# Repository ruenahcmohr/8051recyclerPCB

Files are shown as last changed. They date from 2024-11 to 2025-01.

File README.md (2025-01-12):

# 8051recyclerPCB
External memory card for PLCC 8051 OTP processors

PCB designed for recycling OTP PLCC 8051 chips. 

Becasue using the 8051 with external memory burns off most of the ports, I have added two chips that use the external RAM space for an input and output port. Any write to external memory will go to the dedicated output port, and any read from external memory will read the dedicated input port.

(I hope your fine with the in-chip ram :] )

ERATTA:

- The output chip needs to be 74xx374 or another pin compatible chip but sure the heck not the 74xx373
- Oh, maybe those serial leds ought to be active low eh?
- Ya know that trace to that top decoupling cap dunn't need to be only 10 thou.

IMPROVA:

- Could there please be a mark on the common cathode pin of that damn led?
- Could someone please mark the xtal pin for extern clock input?
- Ya know that trace to that top decoupling cap dunn't need to be only 10 thou.
- break out pins 1, 12, 23, 34 to pads incase they need bodge connections
- align the pin 27 connection with VCC for easier bridging to use 2764 roms. (haha wait no, there are only 28 pins)

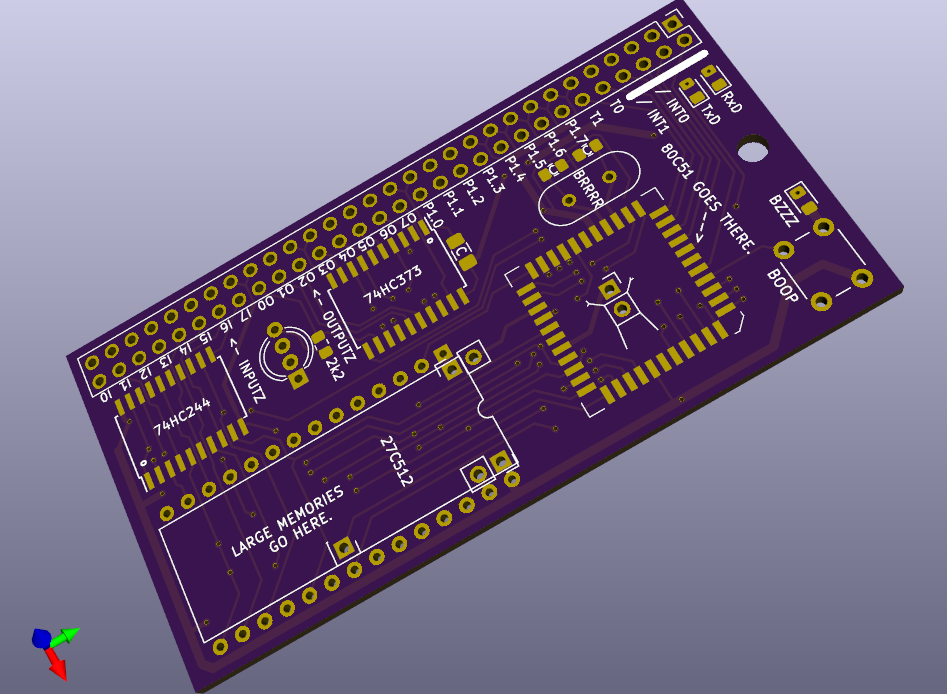
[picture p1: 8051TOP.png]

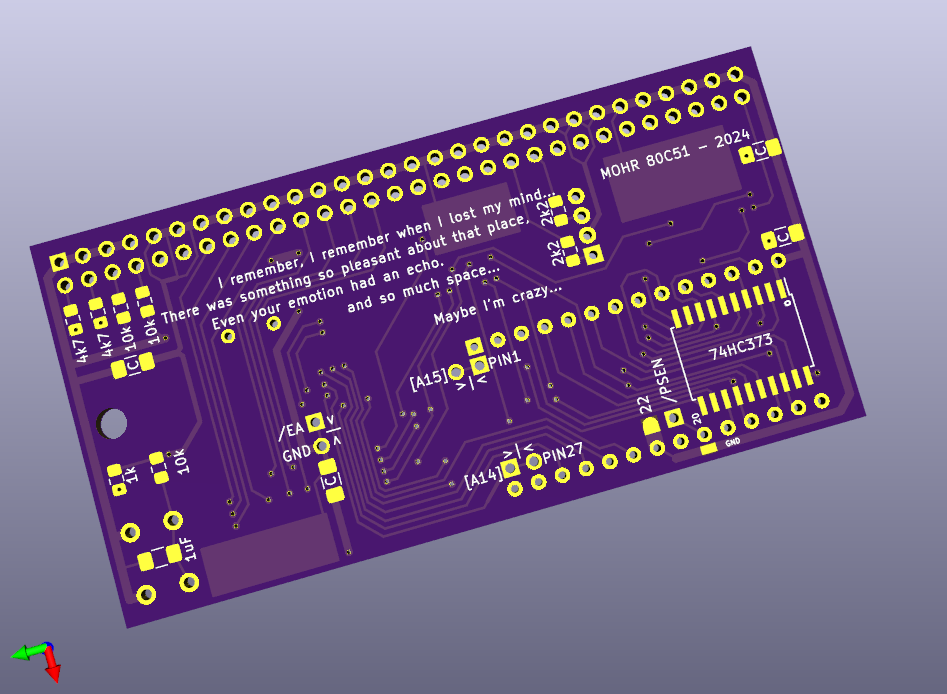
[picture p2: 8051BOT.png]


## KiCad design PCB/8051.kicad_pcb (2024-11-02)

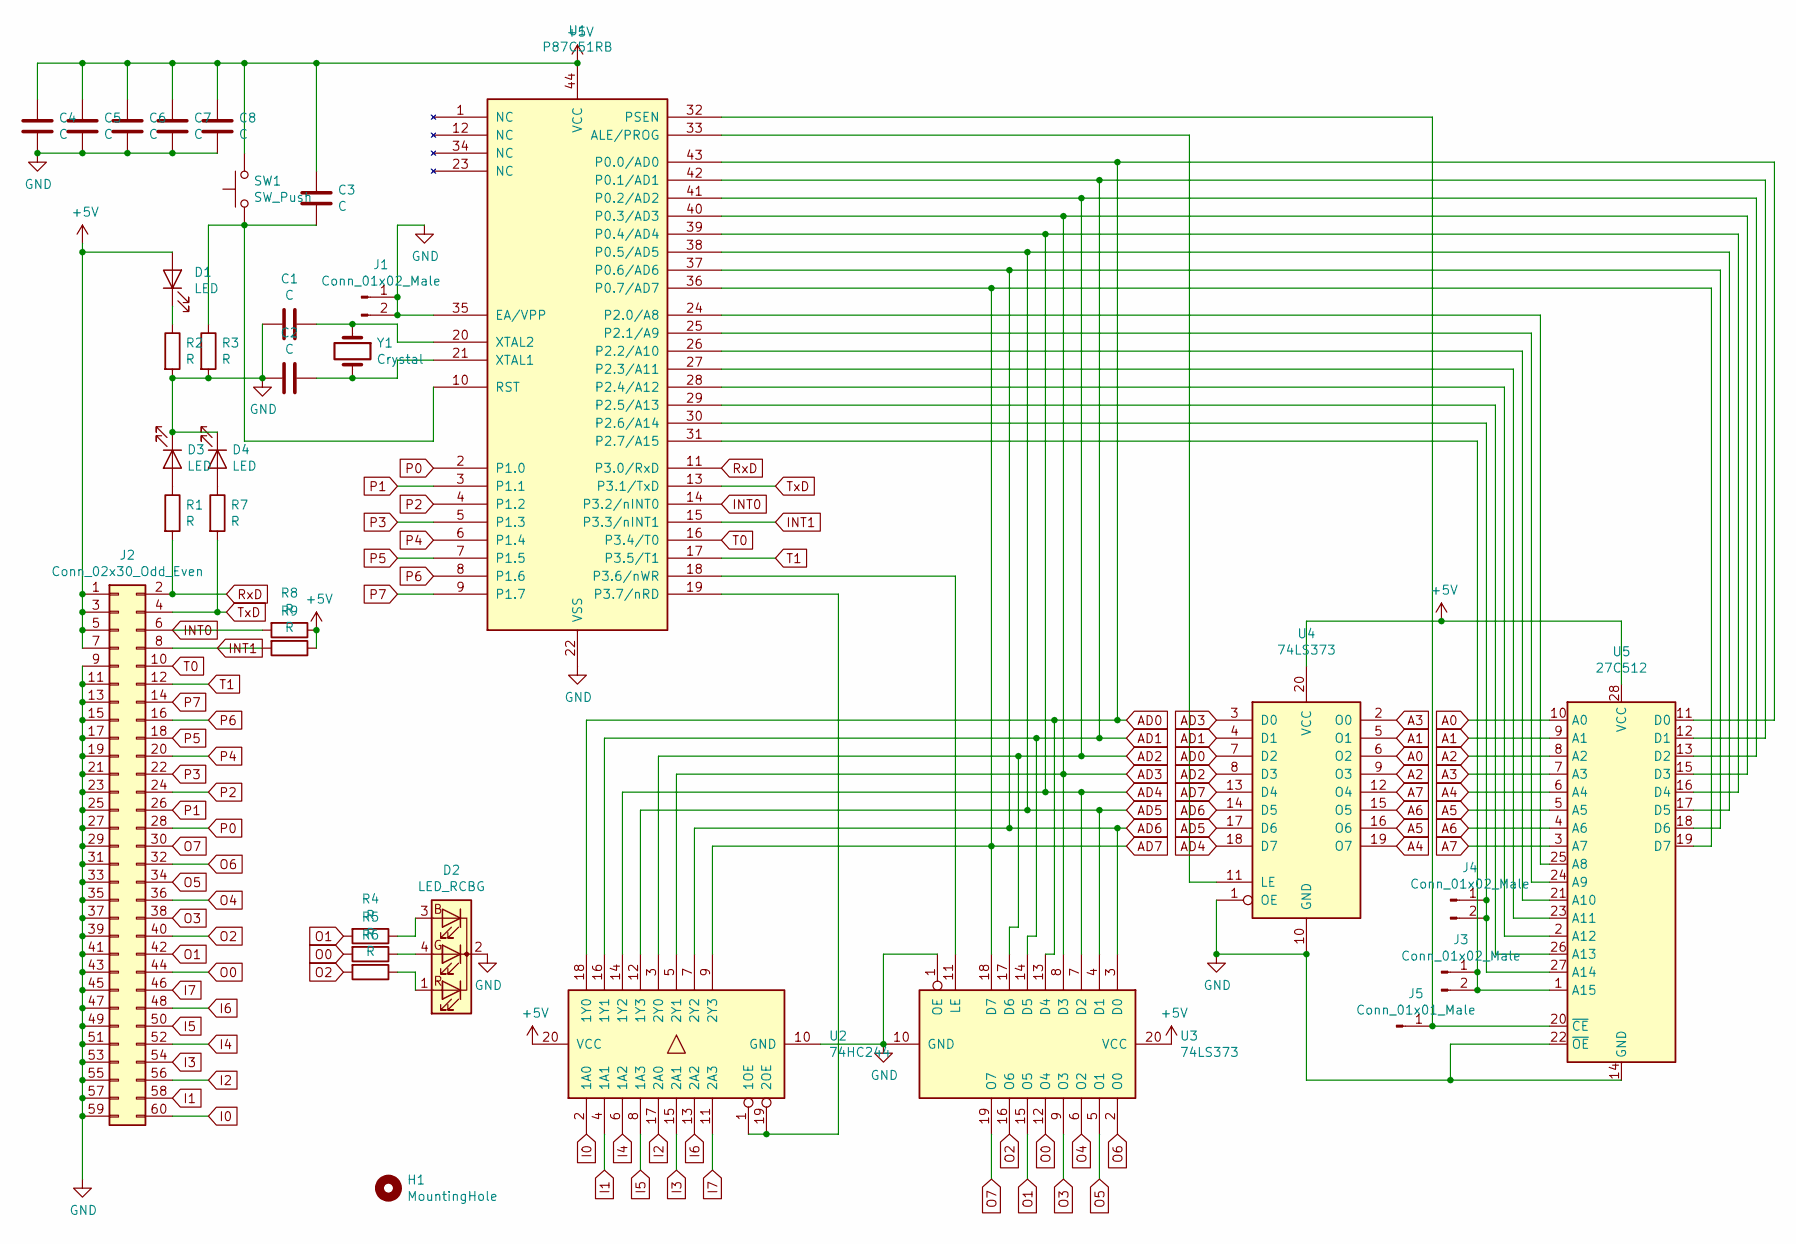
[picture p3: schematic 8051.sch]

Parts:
C1, C2: C; C_0805_2012Metric_Pad1.15x1.40mm_HandSolder
C3, C4, C5, C6, C7, C8: C; C_1206_3216Metric_Pad1.42x1.75mm_HandSolder
D1, D3, D4: LED; LED_0805_2012Metric_Pad1.15x1.40mm_HandSolder
D2: LED_RCBG; LED_D5.0mm-4_RGB_Wide_Pins
H1: MountingHole; MountingHole_3.2mm_M3
J1, J3, J4: Conn_01x02_Male; PinSocket_1x02_P2.54mm_Vertical
J2: Conn_02x30_Odd_Even; PinHeader_2x30_P2.54mm_Vertical
J5: Conn_01x01_Male; PinSocket_1x01_P2.54mm_Vertical
R1, R2, R3, R4, R5, R6, R7, R8, R9: R; R_0805_2012Metric_Pad1.15x1.40mm_HandSolder
SW1: SW_Push; SW_PUSH_6mm
U1: P87C51RB; PLCC-44
U2: 74HC244; SOIC-20W_7.5x12.8mm_P1.27mm
U3, U4: 74LS373; SOIC-20W_7.5x12.8mm_P1.27mm
U5: 27C512; DIP-28_W15.24mm
Y1: Crystal; Crystal_HC49-4H_Vertical

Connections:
+5V: C3.1, C4.1, C5.1, C6.1, C7.1, C8.1, D1.2 (A), J2.1, J2.3, J2.5, J2.7, R8.1, R9.1, SW1.1, U1.44 (VCC), U2.20 (VCC), U3.20 (VCC), U4.20 (VCC), U5.28 (VCC)
A0: U4.6 (O2), U5.10 (A0)
A1: U4.5 (O1), U5.9 (A1)
A2: U4.9 (O3), U5.8 (A2)
A3: U4.2 (O0), U5.7 (A3)
A4: U4.19 (O7), U5.6 (A4)
A5: U4.16 (O6), U5.5 (A5)
A6: U4.15 (O5), U5.4 (A6)
A7: U4.12 (O4), U5.3 (A7)
AD0: U1.43 (P0.0/AD0), U2.18 (1Y0), U3.13 (D4), U4.7 (D2), U5.11 (D0)
AD1: U1.42 (P0.1/AD1), U2.16 (1Y1), U3.14 (D5), U4.4 (D1), U5.12 (D1)
AD2: U1.41 (P0.2/AD2), U2.3 (2Y0), U3.17 (D6), U4.8 (D3), U5.13 (D2)
AD3: U1.40 (P0.3/AD3), U2.5 (2Y1), U3.8 (D3), U4.3 (D0), U5.15 (D3)
AD4: U1.39 (P0.4/AD4), U2.14 (1Y2), U3.7 (D2), U4.18 (D7), U5.16 (D4)
AD5: U1.38 (P0.5/AD5), U2.12 (1Y3), U3.4 (D1), U4.17 (D6), U5.17 (D5)
AD6: U1.37 (P0.6/AD6), U2.7 (2Y2), U3.3 (D0), U4.14 (D5), U5.18 (D6)
AD7: U1.36 (P0.7/AD7), U2.9 (2Y3), U3.18 (D7), U4.13 (D4), U5.19 (D7)
GND: C1.2, C2.2, C4.2, C5.2, C6.2, C7.2, C8.2, D2.2 (K), D3.1 (K), D4.1 (K), J1.1, J1.2, J2.9, J2.11, J2.13, J2.15, J2.17, J2.19, J2.21, J2.23, J2.25, J2.27, J2.29, J2.31, J2.33, J2.35, J2.37, J2.39, J2.41, J2.43, J2.45, J2.47, J2.49, J2.51, J2.53, J2.55, J2.57, J2.59, R2.2, R3.2, U1.22 (VSS), U1.35 (EA/VPP), U2.10 (GND), U3.1 (OE), U3.10 (GND), U4.1 (OE), U4.10 (GND), U5.14 (GND), U5.22 (~OE)
I0: J2.60, U2.2 (1A0)
I1: J2.58, U2.4 (1A1)
I2: J2.56, U2.17 (2A0)
I3: J2.54, U2.15 (2A1)
I4: J2.52, U2.6 (1A2)
I5: J2.50, U2.8 (1A3)
I6: J2.48, U2.13 (2A2)
I7: J2.46, U2.11 (2A3)
INT0: J2.6, R8.2, U1.14 (P3.2/nINT0)
INT1: J2.8, R9.2, U1.15 (P3.3/nINT1)
unnamed: C1.1, U1.20 (XTAL2), Y1.1
unnamed: C2.1, U1.21 (XTAL1), Y1.2
unnamed: C3.2, R3.1, SW1.2, U1.10 (RST)
unnamed: D1.1 (K), R2.1
unnamed: D2.1 (RA), R6.1
unnamed: D2.3 (BA), R4.1
unnamed: D2.4 (GA), R5.1
unnamed: D3.2 (A), R1.1
unnamed: D4.2 (A), R7.1
unnamed: J3.1, J3.2, U1.31 (P2.7/A15), U5.1 (A15)
unnamed: J4.1, J4.2, U1.30 (P2.6/A14), U5.27 (A14)
unnamed: J5.1, U1.32 (PSEN), U5.20 (~CE)
unnamed: U1.18 (P3.6/nWR), U3.11 (LE)
unnamed: U1.19 (P3.7/nRD), U2.1 (1OE), U2.19 (2OE)
unnamed: U1.24 (P2.0/A8), U5.25 (A8)
unnamed: U1.25 (P2.1/A9), U5.24 (A9)
unnamed: U1.26 (P2.2/A10), U5.21 (A10)
unnamed: U1.27 (P2.3/A11), U5.23 (A11)
unnamed: U1.28 (P2.4/A12), U5.2 (A12)
unnamed: U1.29 (P2.5/A13), U5.26 (A13)
unnamed: U1.33 (ALE/PROG), U4.11 (LE)
O0: J2.44, R5.2, U3.12 (O4)
O1: J2.42, R4.2, U3.15 (O5)
O2: J2.40, R6.2, U3.16 (O6)
O3: J2.38, U3.9 (O3)
O4: J2.36, U3.6 (O2)
O5: J2.34, U3.5 (O1)
O6: J2.32, U3.2 (O0)
O7: J2.30, U3.19 (O7)
P0: J2.28, U1.2 (P1.0)
P1: J2.26, U1.3 (P1.1)
P2: J2.24, U1.4 (P1.2)
P3: J2.22, U1.5 (P1.3)
P4: J2.20, U1.6 (P1.4)
P5: J2.18, U1.7 (P1.5)
P6: J2.16, U1.8 (P1.6)
P7: J2.14, U1.9 (P1.7)
RxD: J2.2, R1.2, U1.11 (P3.0/RxD)
T0: J2.10, U1.16 (P3.4/T0)
T1: J2.12, U1.17 (P3.5/T1)
TxD: J2.4, R7.2, U1.13 (P3.1/TxD)

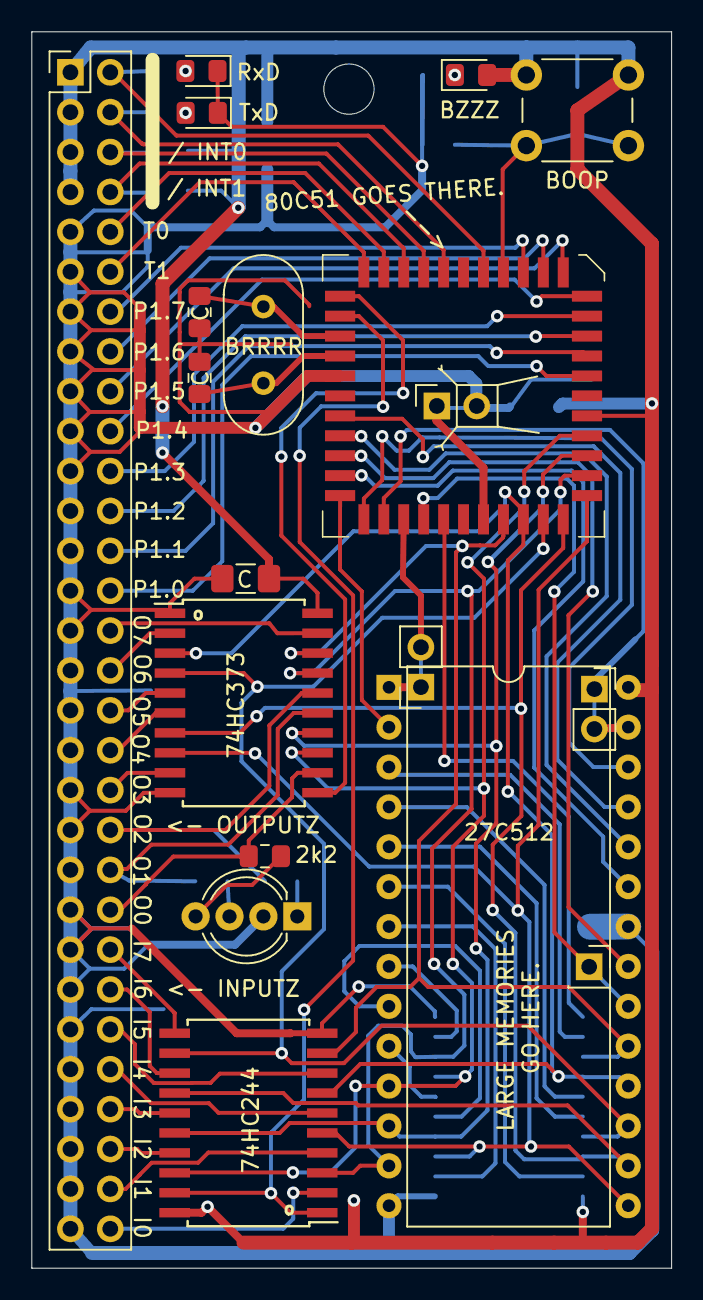
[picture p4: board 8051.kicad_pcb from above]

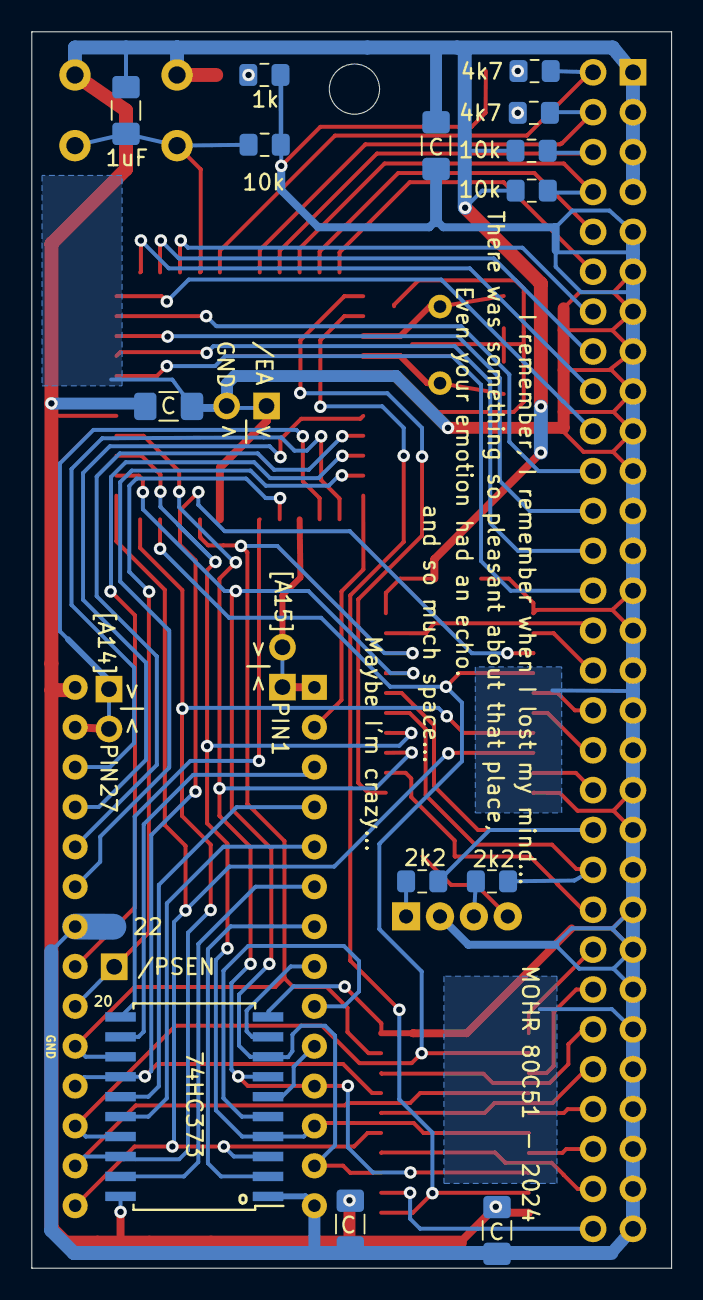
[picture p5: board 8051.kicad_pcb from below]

Board: 2 copper layers, 40.8 x 78.8 mm, 34 parts (14 on the bottom side), 69 nets.

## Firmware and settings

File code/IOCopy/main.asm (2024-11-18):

;--------------------------------------------------------
; File Created by SDCC : free open source ANSI-C Compiler
; Version 4.0.0 #11528 (Linux)
;--------------------------------------------------------
	.module main
	.optsdcc -mmcs51 --model-small
	
;--------------------------------------------------------
; Public variables in this module
;--------------------------------------------------------
	.globl _main
	.globl _Delay
	.globl _B_7
	.globl _B_6
	.globl _B_5
	.globl _B_4
	.globl _B_3
	.globl _B_2
	.globl _B_1
	.globl _B_0
	.globl _ACC_7
	.globl _ACC_6
	.globl _ACC_5
	.globl _ACC_4
	.globl _ACC_3
	.globl _ACC_2
	.globl _ACC_1
	.globl _ACC_0
	.globl _CF
	.globl _CR
	.globl _CCF4
	.globl _CCF3
	.globl _CCF2
	.globl _CCF1
	.globl _CCF0
	.globl _CY
	.globl _AC
	.globl _F0
	.globl _RS1
	.globl _RS0
	.globl _OV
	.globl _P
	.globl _TF2
	.globl _EXF2
	.globl _RCLK
	.globl _TCLK
	.globl _EXEN2
	.globl _TR2
	.globl _C_T2
	.globl _CP_RL2
	.globl _PPC
	.globl _PT2
	.globl _PS
	.globl _PT1
	.globl _PX1
	.globl _PT0
	.globl _PX0
	.globl _P3_7
	.globl _P3_6
	.globl _P3_5
	.globl _P3_4
	.globl _P3_3
	.globl _P3_2
	.globl _P3_1
	.globl _P3_0
	.globl _EA
	.globl _EC
	.globl _ET2
	.globl _ES
	.globl _ET1
	.globl _EX1
	.globl _ET0
	.globl _EX0
	.globl _P2_7
	.globl _P2_6
	.globl _P2_5
	.globl _P2_4
	.globl _P2_3
	.globl _P2_2
	.globl _P2_1
	.globl _P2_0
	.globl _SM0
	.globl _SM1
	.globl _SM2
	.globl _REN
	.globl _TB8
	.globl _RB8
	.globl _TI
	.globl _RI
	.globl _P1_7
	.globl _P1_6
	.globl _P1_5
	.globl _P1_4
	.globl _P1_3
	.globl _P1_2
	.globl _P1_1
	.globl _P1_0
	.globl _TF1
	.globl _TR1
	.globl _TF0
	.globl _TR0
	.globl _IE1
	.globl _IT1
	.globl _IE0
	.globl _IT0
	.globl _P0_7
	.globl _P0_6
	.globl _P0_5
	.globl _P0_4
	.globl _P0_3
	.globl _P0_2
	.globl _P0_1
	.globl _P0_0
	.globl _CCAP4H
	.globl _CCAP3H
	.globl _CCAP2H
	.globl _CCAP1H
	.globl _CCAP0H
	.globl _CH
	.globl _B
	.globl _CCAP4L
	.globl _CCAP3L
	.globl _CCAP2L
	.globl _CCAP1L
	.globl _CCAP0L
	.globl _CL
	.globl _ACC
	.globl _CCAPM4
	.globl _CCAPM3
	.globl _CCAPM2
	.globl _CCAPM1
	.globl _CCAPM0
	.globl _CMOD
	.globl _CCON
	.globl _PSW
	.globl _TH2
	.globl _TL2
	.globl _RCAP2H
	.globl _RCAP2L
	.globl _T2MOD
	.globl _T2CON
	.globl _SADEN
	.globl _IP
	.globl _IPH
	.globl _P3
	.globl _SADDR
	.globl _IE
	.globl _AUXR1
	.globl _P2
	.globl _SBUF
	.globl _SCON
	.globl _P1
	.globl _AUXR
	.globl _TH1
	.globl _TH0
	.globl _TL1
	.globl _TL0
	.globl _TMOD
	.globl _TCON
	.globl _PCON
	.globl _DPH
	.globl _DPL
	.globl _SP
	.globl _P0
	.globl _IO
;--------------------------------------------------------
; special function registers
;--------------------------------------------------------
	.area RSEG    (ABS,DATA)
	.org 0x0000
_P0	=	0x0080
_SP	=	0x0081
_DPL	=	0x0082
_DPH	=	0x0083
_PCON	=	0x0087
_TCON	=	0x0088
_TMOD	=	0x0089
_TL0	=	0x008a
_TL1	=	0x008b
_TH0	=	0x008c
_TH1	=	0x008d
_AUXR	=	0x008e
_P1	=	0x0090
_SCON	=	0x0098
_SBUF	=	0x0099
_P2	=	0x00a0
_AUXR1	=	0x00a2
_IE	=	0x00a8
_SADDR	=	0x00a9
_P3	=	0x00b0
_IPH	=	0x00b7
_IP	=	0x00b8
_SADEN	=	0x00b9
_T2CON	=	0x00c8
_T2MOD	=	0x00c9
_RCAP2L	=	0x00ca
_RCAP2H	=	0x00cb
_TL2	=	0x00cc
_TH2	=	0x00cd
_PSW	=	0x00d0
_CCON	=	0x00d8
_CMOD	=	0x00d9
_CCAPM0	=	0x00da
_CCAPM1	=	0x00db
_CCAPM2	=	0x00dc
_CCAPM3	=	0x00dd
_CCAPM4	=	0x00de
_ACC	=	0x00e0
_CL	=	0x00e9
_CCAP0L	=	0x00ea
_CCAP1L	=	0x00eb
_CCAP2L	=	0x00ec
_CCAP3L	=	0x00ed
_CCAP4L	=	0x00ee
_B	=	0x00f0
_CH	=	0x00f9
_CCAP0H	=	0x00fa
_CCAP1H	=	0x00fb
_CCAP2H	=	0x00fc
_CCAP3H	=	0x00fd
_CCAP4H	=	0x00fe
;--------------------------------------------------------
; special function bits
;--------------------------------------------------------
	.area RSEG    (ABS,DATA)
	.org 0x0000
_P0_0	=	0x0080
_P0_1	=	0x0081
_P0_2	=	0x0082
_P0_3	=	0x0083
_P0_4	=	0x0084
_P0_5	=	0x0085
_P0_6	=	0x0086
_P0_7	=	0x0087
_IT0	=	0x0088
_IE0	=	0x0089
_IT1	=	0x008a
_IE1	=	0x008b
_TR0	=	0x008c
_TF0	=	0x008d
_TR1	=	0x008e
_TF1	=	0x008f
_P1_0	=	0x0090
_P1_1	=	0x0091
_P1_2	=	0x0092
_P1_3	=	0x0093
_P1_4	=	0x0094
_P1_5	=	0x0095
_P1_6	=	0x0096
_P1_7	=	0x0097
_RI	=	0x0098
_TI	=	0x0099
_RB8	=	0x009a
_TB8	=	0x009b
_REN	=	0x009c
_SM2	=	0x009d
_SM1	=	0x009e
_SM0	=	0x009f
_P2_0	=	0x00a0
_P2_1	=	0x00a1
_P2_2	=	0x00a2
_P2_3	=	0x00a3
_P2_4	=	0x00a4
_P2_5	=	0x00a5
_P2_6	=	0x00a6
_P2_7	=	0x00a7
_EX0	=	0x00a8
_ET0	=	0x00a9
_EX1	=	0x00aa
_ET1	=	0x00ab
_ES	=	0x00ac
_ET2	=	0x00ad
_EC	=	0x00ae
_EA	=	0x00af
_P3_0	=	0x00b0
_P3_1	=	0x00b1
_P3_2	=	0x00b2
_P3_3	=	0x00b3
_P3_4	=	0x00b4
_P3_5	=	0x00b5
_P3_6	=	0x00b6
_P3_7	=	0x00b7
_PX0	=	0x00b8
_PT0	=	0x00b9
_PX1	=	0x00ba
_PT1	=	0x00bb
_PS	=	0x00bc
_PT2	=	0x00bd
_PPC	=	0x00be
_CP_RL2	=	0x00c8
_C_T2	=	0x00c9
_TR2	=	0x00ca
_EXEN2	=	0x00cb
_TCLK	=	0x00cc
_RCLK	=	0x00cd
_EXF2	=	0x00ce
_TF2	=	0x00cf
_P	=	0x00d0
_OV	=	0x00d2
_RS0	=	0x00d3
_RS1	=	0x00d4
_F0	=	0x00d5
_AC	=	0x00d6
_CY	=	0x00d7
_CCF0	=	0x00d8
_CCF1	=	0x00d9
_CCF2	=	0x00da
_CCF3	=	0x00db
_CCF4	=	0x00dc
_CR	=	0x00de
_CF	=	0x00df
_ACC_0	=	0x00e0
_ACC_1	=	0x00e1
_ACC_2	=	0x00e2
_ACC_3	=	0x00e3
_ACC_4	=	0x00e4
_ACC_5	=	0x00e5
_ACC_6	=	0x00e6
_ACC_7	=	0x00e7
_B_0	=	0x00f0
_B_1	=	0x00f1
_B_2	=	0x00f2
_B_3	=	0x00f3
_B_4	=	0x00f4
_B_5	=	0x00f5
_B_6	=	0x00f6
_B_7	=	0x00f7
;--------------------------------------------------------
; overlayable register banks
;--------------------------------------------------------
	.area REG_BANK_0	(REL,OVR,DATA)
	.ds 8
;--------------------------------------------------------
; internal ram data
;--------------------------------------------------------
	.area DSEG    (DATA)
_IO::
	.ds 2
;--------------------------------------------------------
; overlayable items in internal ram 
;--------------------------------------------------------
	.area	OSEG    (OVR,DATA)
	.area	OSEG    (OVR,DATA)
;--------------------------------------------------------
; Stack segment in internal ram 
;--------------------------------------------------------
	.area	SSEG
__start__stack:
	.ds	1

;--------------------------------------------------------
; indirectly addressable internal ram data
;--------------------------------------------------------
	.area ISEG    (DATA)
;--------------------------------------------------------
; absolute internal ram data
;--------------------------------------------------------
	.area IABS    (ABS,DATA)
	.area IABS    (ABS,DATA)
;--------------------------------------------------------
; bit data
;--------------------------------------------------------
	.area BSEG    (BIT)
;--------------------------------------------------------
; paged external ram data
;--------------------------------------------------------
	.area PSEG    (PAG,XDATA)
;--------------------------------------------------------
; external ram data
;--------------------------------------------------------
	.area XSEG    (XDATA)
;--------------------------------------------------------
; absolute external ram data
;--------------------------------------------------------
	.area XABS    (ABS,XDATA)
;--------------------------------------------------------
; external initialized ram data
;--------------------------------------------------------
	.area XISEG   (XDATA)
	.area HOME    (CODE)
	.area GSINIT0 (CODE)
	.area GSINIT1 (CODE)
	.area GSINIT2 (CODE)
	.area GSINIT3 (CODE)
	.area GSINIT4 (CODE)
	.area GSINIT5 (CODE)
	.area GSINIT  (CODE)
	.area GSFINAL (CODE)
	.area CSEG    (CODE)
;--------------------------------------------------------
; interrupt vector 
;--------------------------------------------------------
	.area HOME    (CODE)
__interrupt_vect:
	ljmp	__sdcc_gsinit_startup
;--------------------------------------------------------
; global & static initialisations
;--------------------------------------------------------
	.area HOME    (CODE)
	.area GSINIT  (CODE)
	.area GSFINAL (CODE)
	.area GSINIT  (CODE)
	.globl __sdcc_gsinit_startup
	.globl __sdcc_program_startup
	.globl __start__stack
	.globl __mcs51_genXINIT
	.globl __mcs51_genXRAMCLEAR
	.globl __mcs51_genRAMCLEAR
	.area GSFINAL (CODE)
	ljmp	__sdcc_program_startup
;--------------------------------------------------------
; Home
;--------------------------------------------------------
	.area HOME    (CODE)
	.area HOME    (CODE)
__sdcc_program_startup:
	ljmp	_main
;	return from main will return to caller
;--------------------------------------------------------
; code
;--------------------------------------------------------
	.area CSEG    (CODE)
;------------------------------------------------------------
;Allocation info for local variables in function 'Delay'
;------------------------------------------------------------
;n                         Allocated to registers 
;------------------------------------------------------------
;	main.c:22: void Delay(unsigned int n) {
;	-----------------------------------------
;	 function Delay
;	-----------------------------------------
_Delay:
	ar7 = 0x07
	ar6 = 0x06
	ar5 = 0x05
	ar4 = 0x04
	ar3 = 0x03
	ar2 = 0x02
	ar1 = 0x01
	ar0 = 0x00
	mov	r6,dpl
	mov	r7,dph
00103$:
;	main.c:23: for (; n; n--) NOP();
	mov	a,r6
	orl	a,r7
	jz	00105$
	nop	
	dec	r6
	cjne	r6,#0xff,00117$
	dec	r7
00117$:
	sjmp	00103$
00105$:
;	main.c:24: }
	ret
;------------------------------------------------------------
;Allocation info for local variables in function 'main'
;------------------------------------------------------------
;t                         Allocated to registers r7 
;------------------------------------------------------------
;	main.c:26: void main( void ) {
;	-----------------------------------------
;	 function main
;	-----------------------------------------
_main:
;	main.c:28: IO = (__xdata uint8_t *)0x8000;
	mov	_IO,#0x00
	mov	(_IO + 1),#0x80
;	main.c:32: while(1) {
00102$:
;	main.c:33: t = *IO;
	mov	dptr,#0x8000
	movx	a,@dptr
;	main.c:34: *IO = t;
	mov	r7,a
	mov	dptr,#0x8000
	movx	@dptr,a
;	main.c:36: }
	sjmp	00102$
	.area CSEG    (CODE)
	.area CONST   (CODE)
	.area XINIT   (CODE)
	.area CABS    (ABS,CODE)

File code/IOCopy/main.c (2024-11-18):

/*******************************************************************
                                                                  
 Program description                                              
                                                                  
                                               
                                                                  
********************************************************************/

// ----==[ INCLUDES ]==-----
//#include <8051.h> // Definitions of registers, SFRs and Bits

#include "sdccStupidity.h"
#include <stdint.h>
#include "regc51fx.h"


// ----==[ DEFINES  ]==-----
#define NOP()  __asm  nop __endasm

__xdata unsigned char * __data IO;

void Delay(unsigned int n) {
 for (; n; n--) NOP();
}

void main( void ) {

  IO = (__xdata uint8_t *)0x8000;

  uint8_t t;

 while(1) {
    t = *IO;
    *IO = t;
  }
}

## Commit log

2024-11-02 adding files
    [8051-B_Cu.gbr, 8051-B_Mask.gbr, 8051-B_Paste.gbr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]
2024-11-18 folders and adding example source
    [8051-B_Cu.gbr, 8051-B_Mask.gbr, 8051-B_Paste.gbr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]
